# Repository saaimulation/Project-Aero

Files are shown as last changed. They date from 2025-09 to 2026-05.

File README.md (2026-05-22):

# ST0 — Front Wing Project 🏎️
Designing wings that (almost) qualify for Monaco — CAD → simulation → prototyping → iteration

This repo documents my attempt at designing a 2026-style F1 front wing in Siemens NX while learning more about aerodynamic design, CAD surfacing, manufacturing, and engineering workflows along the way.

What started as a personal aero project quickly became a massive learning experience involving CFD issues, geometry problems, redesigns, failed prints, and incredibly valuable feedback from an Alpine F1 aerodynamicist.

The goal was never to create a perfect F1 wing.  
It was to learn how real engineering development actually works:
- iteration
- problem solving
- criticism
- redesigning
- and occasionally questioning every life decision at 2am

Some ideas worked.  
Some absolutely did not.

But honestly, that’s probably the most realistic part of the whole project.

Grab a coffee (or duct tape) and enjoy the race ;)

---

## 🚦 Engineering Workflow Race

### 🏁 [Practice Lap — CAD in NX](./practice-lap-CAD) ✅ Complete
`[██████████] 100%`  
Creating the baseline front wing geometry in Siemens NX.  
The design takes inspiration from the RB19, while considering upcoming 2026 regulations.  

### 🔴 [Qualifying 1 — Red Flag](./qualifying-1-CFD) ✅ Complete
`[██████████] 100%`  
This is the first attempt of running CFD on my wing! <br>
Met with unexpected difficulties, this is a stepping stone to becoming better. 

### ♟️ [Qualifying 2 — Changing Strategy](./qualifying-2-CFD) 🔄 In Progress 
`[█████-----] 50%` <br>
After some insightful feedback from a real F1 engineer, I've started this lap with fresh tyres.   
Currently designing the 2nd iteration for my front wing!

### [Qualifying 3 — The Finish](./qualifying-3-CFD) ⏳ Planned 
`[----------] 0%` <br>
Running in-depth simulations of my upgraded ST1 front wing

### 🏎️ [Sprint Lap — 3D Printing](./sprint-3D-printing) ✅ Complete
`[██████████] 100%`  
Manufacturing a half-span model of the front wing on the Bambu A1, as well as a larger version for visuals.<br>
These parts will be used for physical testing in the upgraded wind tunnel.  
*psst. There's a free F1 wing model for you inside!*

### 🌬️ [Grand Prix — Wind Tunnel Mark II](./grand-prix-wind-tunnel) 🔄 In Progress 
`[█---------] 10%`  
Testing the 3D-printed wing in a new tunnel with flow visualisation techniques.  
The key aim is to evaluate how closely the tunnel data aligns with CFD predictions.  

### 📊 [Podium Review — Analysis & Iteration](./podium-review-analysis) ⏳ Planned  
`[----------] 0%`  
Documenting the full workflow in a 5-page executive summary report.  
The report compares CFD and wind tunnel results, highlights lessons learned, and sets directions for the next design cycle.  

---

Got feedback, advice, or better duct tape recommendations?  
I’m all ears, the whole point is to learn, improve, and share the journey! 🏎️🦇

**saaimulation**

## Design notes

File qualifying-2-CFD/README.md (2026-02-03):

# 🏎️ Qualifying 2

"ST0 ends Q1 at the 17th position, let's see if the upgrades allow for some better racing"  

Welcome back! Q2!! With feedback and some advice from an F1 engineer!!!

---

## Feedback 🛠️

After sharing ST0 publicly, I received detailed technical feedback from an aerodynamicist currently working at Alpine F1 Team (name withheld). The review focused on regulation compliance, aerodynamic intent, CAD surface quality and CFD readiness.

### Overall assessment 📊
• The concept is strong for a second-year undergraduate project and technically suitable for CFD.  
• However, I was advised not to proceed with CFD yet, as the current geometry would not provide a meaningful aerodynamic baseline.  
• Refinement of the design should come before any simulation work.

### Regulations and concept 📐
• The wing is not currently FIA 2026 legal due to being configured as a four-element design.  
• A three-element front wing was recommended.  
• Regulation volumes should be created early in the design process to define legality and aero intent from the start.  
• Using regulation volumes would also help resolve issues such as excessive span and undersized endplates.

### Profiles and spanwise loading 🌬️
• The airfoil sections were identified as too thin for realistic aerodynamic loading.  
• Spanwise loading is heavily biased towards the centreline, reduces at mid-span, then increases again near the endplate.  
• This likely creates opposing vortical structures that remove energy from the flow rather than serving a clear downstream purpose.  
• I was encouraged to think more deliberately about where the flow is intended to go, how it interacts with the tyre wake, and how it feeds the floor.

### Surface quality and CAD approach 🧩
• Several mirrored and intersecting surfaces lack tangential continuity, creating geometric discontinuities.  
• A minimum of G1 continuity should be maintained across all surfaces.  
• In professional F1 environments, G2 or G3 continuity is typically targeted, though G1 is acceptable for this project.  
• Using lofts rather than sweeps was recommended, with three to four controlled sections to maintain surface quality and reduce unnecessary curvature.

### Endplates and footplates 🚧
• The endplates were highlighted as the weakest area of the design and require significant rework.  
• Discontinuities between the main body and footplates are likely to cause local flow stagnation and contaminate downstream flow into the floor.  
• Both inboard and outboard footplates are too thin, contributing to CFD geometry issues.  
• Some regions show unexpected local thickness, likely due to filleting or surface construction errors.

### Nose and main body 🧱
• The nose was described as overly flat and undersized relative to the aerodynamic loading it generates.  
• A slightly larger and more volumetric nose was suggested to improve flow management and continuity into the wing elements.

### CFD guidance 💻
• Although the geometry could technically be meshed, proceeding with CFD now would not be productive.  
• The priority should be improving surface continuity, thickness distribution and aerodynamic intent.  
• CFD should be used later to validate a cleaner and more efficient baseline.

---

## TL;DR 🧠🏎️

• Feedback came from an Alpine F1 aerodynamicist (name withheld out of respect).  
• The wing is CFD-able but not worth simulating yet due to inefficiency and geometry issues.  
• Major improvements needed in regulation compliance, surface continuity and aero intent.  
• Endplates and thickness distribution are the main weaknesses.  
• Concept is strong for my level and worth refining before CFD.

Despite the inefficiencies, the feedback concluded that the work is very strong for my level and demonstrates a high degree of ambition and iteration, well beyond a typical second-year undergraduate project.

## What’s Next – ST1 Roadmap 🧭🏎️

The next iteration (ST1) will focus on refining the concept into a regulation-led, CFD-ready baseline.

• Rebuild the front wing around FIA 2026 regulation volumes to ensure legality from the outset.  
• Reduce the configuration to a three-element wing and redefine element stacking and slot gaps.  
• Increase airfoil thickness to support realistic aerodynamic loading and improve flow robustness.  
• Rework spanwise loading distribution to remove opposing vortical structures and define clearer downstream intent.  
• Redesign endplates and footplates to improve continuity, reduce stagnation, and deliver cleaner flow to the floor.  
• Improve surface quality across all components, targeting full G1 continuity with smoother loft-driven geometry.  
• Adjust nose geometry to improve volumetric continuity and flow management into the wing elements.  
• Clean and simplify CAD topology to remove unintended thickness changes and prepare for meshing.  

Once these changes are implemented, ST1 will be used as the first meaningful CFD baseline, focusing on pressure distribution, flow attachment, and qualitative validation before further optimisation.

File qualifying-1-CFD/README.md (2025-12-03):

# 🏎️ Qualifying 1  

"And here we are, lights out on the next stage of Project: Aero! The CAD lap is in the books, ST0 has rolled out of the garage, and it’s heading straight into the CFD arena. No wind tunnel, no factory-scale computers. Just me, SimScale, and a very nervous laptop fan."  

This part of the project is all about finding out if my RB19-inspired, regulation-legal, student-version-of-NX front wing can actually generate downforce… or if I’ve just built a very stylish drag machine.  

### 🎯 Goals  

- Import the geometry into SimScale and generate a clean mesh.  
- Run airflow simulations at baseline F1 speeds (~50 m/s to start).  
- Visualise pressure, velocity, and streamlines to understand behaviour.  
- See if the slot gaps and flap angles really do their job, or if I’ve engineered the world’s most expensive desk fan.  

### 🛠️ Tools  

- **SimScale** (meshing + solver + post-processing in one platform)  

---

Think of this as Q1 in qualifying: the aim isn’t to smash records yet, but to get a solid lap on the board. Once the pipeline works, we’ll push harder in Q2 and Q3 which means higher speeds, setup tweaks, and hopefully a lot more downforce.  

### 🧠 What I Expect to See  

- A clear pressure differential across the wing (high pressure above, low pressure below), confirming it generates downforce rather than lift.  
- Streamlines remaining attached through the slot gaps, if they detach too early, the wing stalls and performance drops off a cliff.  
- Evidence of Y250 vortex structures forming near the central section, helping control airflow downstream.  
- The outer flaps biasing flow outward around the tyres (like the RB19), reducing wake turbulence and drag.  
- Boundary layers that stay thin and attached, if they thicken or separate too much, I’ll know my flap angles were too aggressive.  

If I see these features, I’ll know the design philosophy was on the right track. If not… well, back to the CAD garage for ST1.  

---

# SimScale notes

So we begin. Starting off by importing my STL file into the software.

### Import and scale

<div>
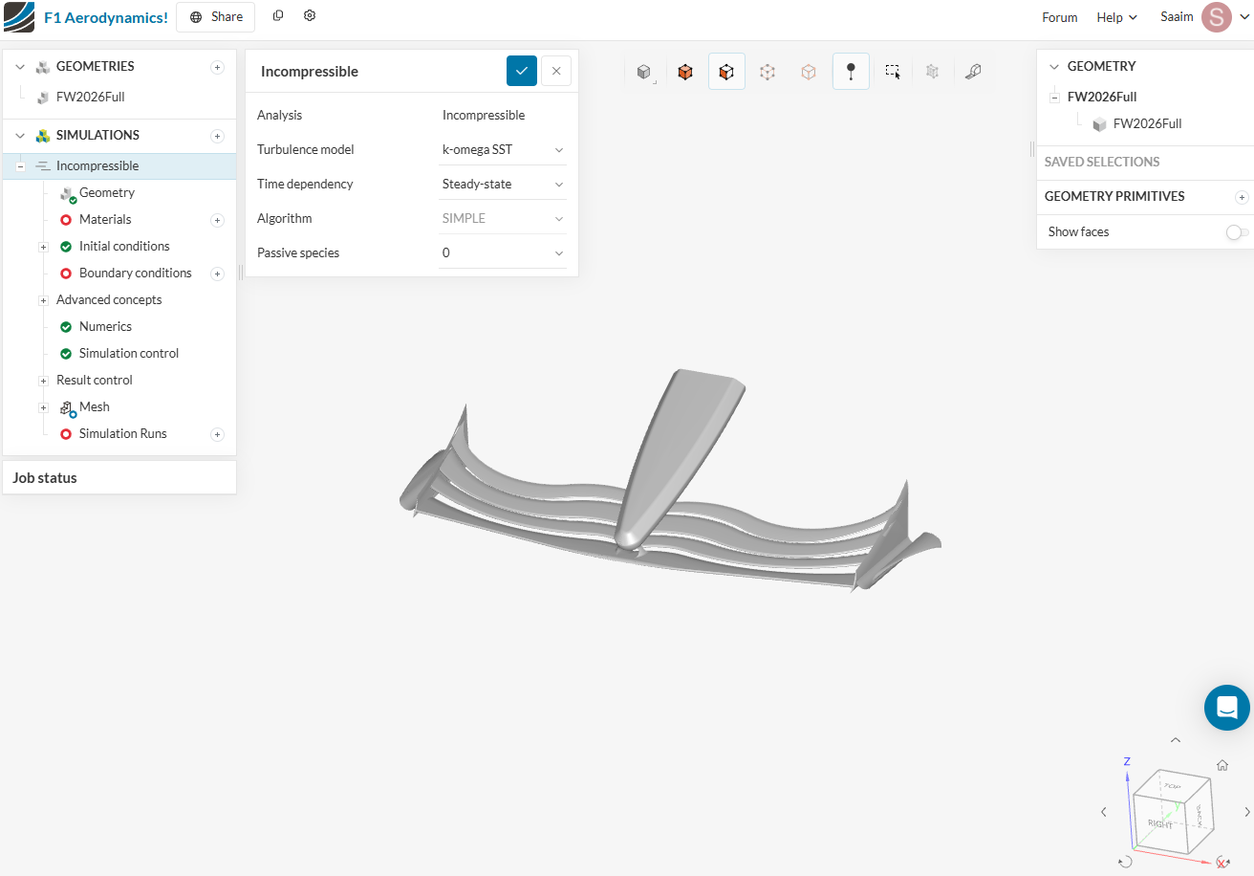
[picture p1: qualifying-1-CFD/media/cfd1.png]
Initial import
  
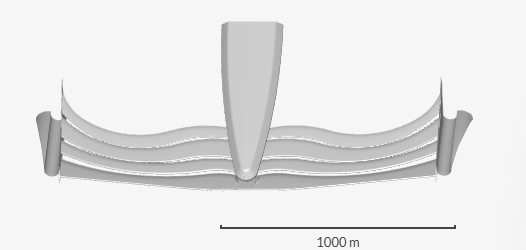
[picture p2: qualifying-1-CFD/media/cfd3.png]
Scale check
  
</div>

Scaled the model by a factor of **0.001** to convert m → mm.

<div>
  After scaling
</div>

### Setup

Created an external flow volume and set up an incompressible simulation.

<div>
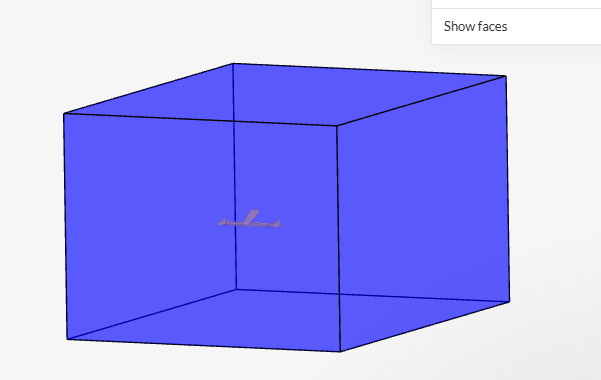
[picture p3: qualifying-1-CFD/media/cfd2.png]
External flow region
  
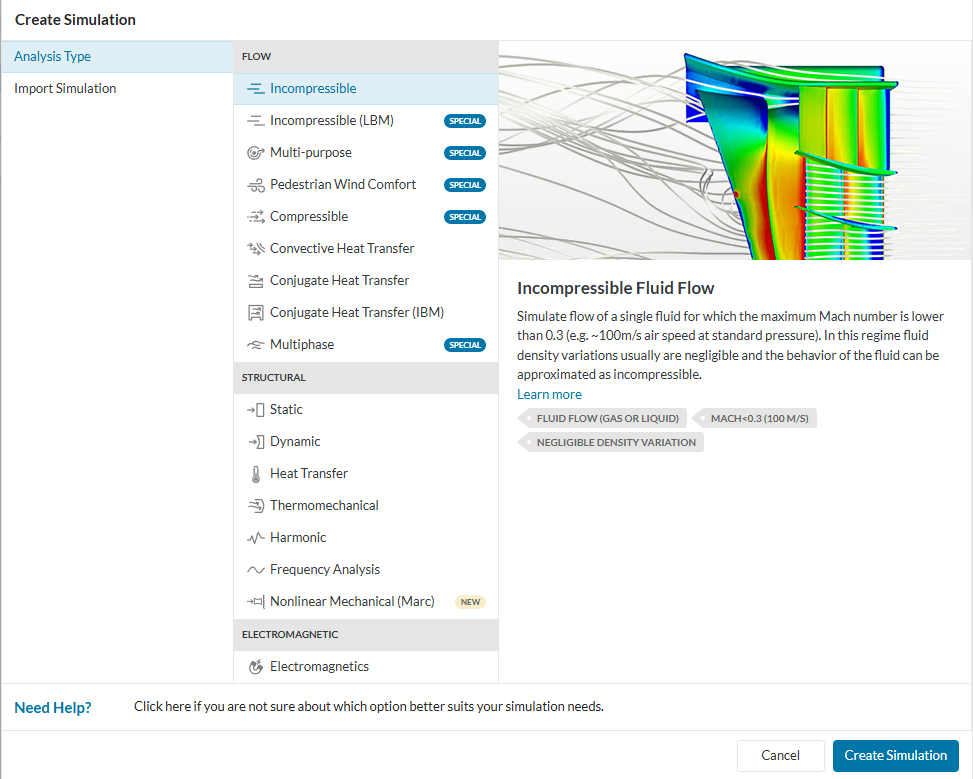
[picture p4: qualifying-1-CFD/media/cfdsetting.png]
Simulation settings
  
</div>

### What went wrong 🤕

Then came the errors. Many of them.

<div>
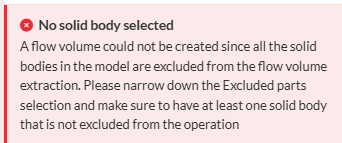
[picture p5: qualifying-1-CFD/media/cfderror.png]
Error 1
  
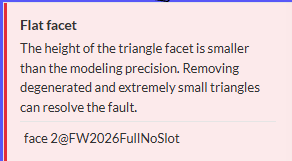
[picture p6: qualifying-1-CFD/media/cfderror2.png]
Error 2
  
</div>
<div>
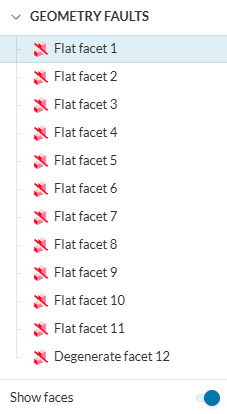
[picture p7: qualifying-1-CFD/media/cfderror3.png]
Error 3
  
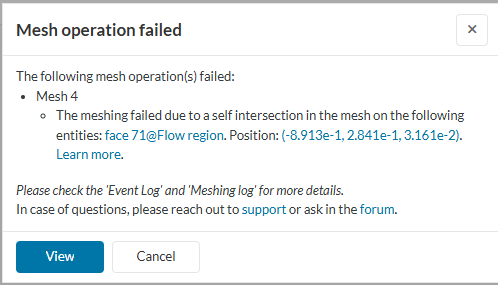
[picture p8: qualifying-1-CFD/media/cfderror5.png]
Error 5
  
</div>

Tried everything I could think of: tutorials, docs and forums. Tweaked the model, repaired faces, changed the flow region, removed tiny slots.  
Still no success.  After four days it was clear the blocker was geometry integrity, not the physics setup.

### Resources I used while debugging 🤖

- SimScale forum thread on [assigning materials to original geometry vs flow region](https://www.simscale.com/forum/t/my-original-geometry-and-flow-region-assigning-materials/99541/3)
- Official tutorial: [Formula Student car — Edit a copy](https://www.simscale.com/docs/tutorials/formula-student-car/#edit-a-copy)
- Knowledge base: [Intersections in the model](https://www.simscale.com/knowledge-base/intersections-in-model)
- Forum discussion: [Flat facet error](https://www.simscale.com/forum/t/flat-facet-error-and/90315)
- Video guide: [External aerodynamics in SimScale](https://www.youtube.com/watch?v=WsPy_TJotv4)
  
---

### Taking a step back ⏪

I was spending too long debugging and accepted the root cause: my CAD needed work.   
It felt like going backwards, but fixing the geometry was the fastest way forward. 

Unfortunately, ST0 did not qualify in Q1...

# Back to the garage for Q2!

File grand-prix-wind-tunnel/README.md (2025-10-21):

# 🌬️ Grand Prix — Wind Tunnel Mark II

*"Welcome to race day! In five lights time, the Project Aero Grand Prix will be starting. It's lights out and away we go!"*

Hello again! This time the final lap has finally begun! Designing and building the Mark II wind tunnel to test the 3D-printed 2026 front wing. Smoother flow, cleaner data, faster feedback. The real race starts here.

## 🧠 Understanding Wind Tunnels 

First thing on the agenda: RESEARCH   

I have to find out how these wind tunnels work! Learning and thinking about how to design and produce it is a step in every process of bringing something to life!
So here is that I have learned:   
1.

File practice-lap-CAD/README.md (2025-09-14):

# 🏁 Practice Lap — CAD  

“And away we go! The first lap of Project: Aero. The garage doors are open, the tools are out, and the focus is on turning rough ideas into geometry that can actually be tested.”  

Hi, Saaim here👋 Welcome to the practice lap! This stage begins with the 2026 F1 regulations 📜 The new rules bring narrower cars, simplified aero and movable elements, all designed to reduce dirty air and keep racing close. Within those constraints, the target is to create a baseline front wing in Siemens NX.  

NX was chosen as the baseline CAD tool after advice from industry engineers, with CATIA as a natural future step once I’m confident in NX.

I thought about including the new active aerodynamics — Z-mode for high downforce in corners and X-mode for low drag on the straights — but decided to keep it simpler for now. That can be a future project 👀  

So before any sketches or CAD, it’s time to check the rulebook!

### 📜 FIA 2026 Front Wing Regulations (condensed)

- Maximum width reduced to **1900 mm** (100 mm narrower than 2022–25).  
- Must be a **single assembly**: mainplane, flaps, endplates, pylons.  
- Up to **4 profiles** allowed, with a fixed flap rotation axis.  
- Endplates must cover the FIA’s mandated reference boxes in both top and side views.  
- Smooth transition into the nose, with limited fillet radius (≤ 25 mm).  
- Active aero (Z/X modes) is permitted, but not included in my first version.  

**What this means for me**  
- I need to design within a narrower span and tighter FIA boxes.  
- Endplates must stay simple and legal; no overcomplicated tricks.  
- Flap geometry has to respect the fixed hinge axis.  
- Active aero is allowed in the regs, but I’ll skip it for now.  
- My target is a clean, rule-aware baseline wing that can be tested in CFD and the tunnel.  

📂 The full regulations can be found in this repo:  
`/practice-lap-CAD/fia_2026_technical_regulations.pdf`

---

### 🔎 Visual references (FIA concept)

**Front view**  
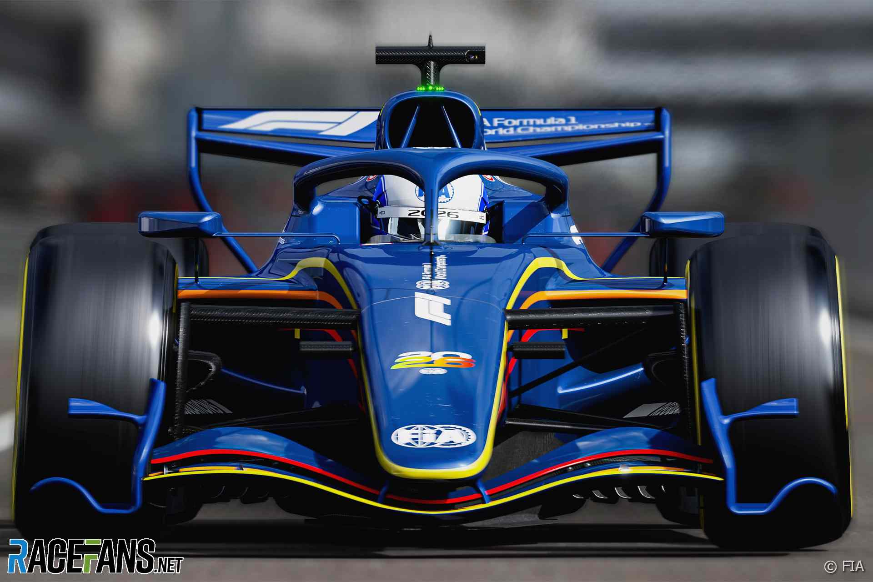
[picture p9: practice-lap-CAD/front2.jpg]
Front view


**Three-quarter renders**  
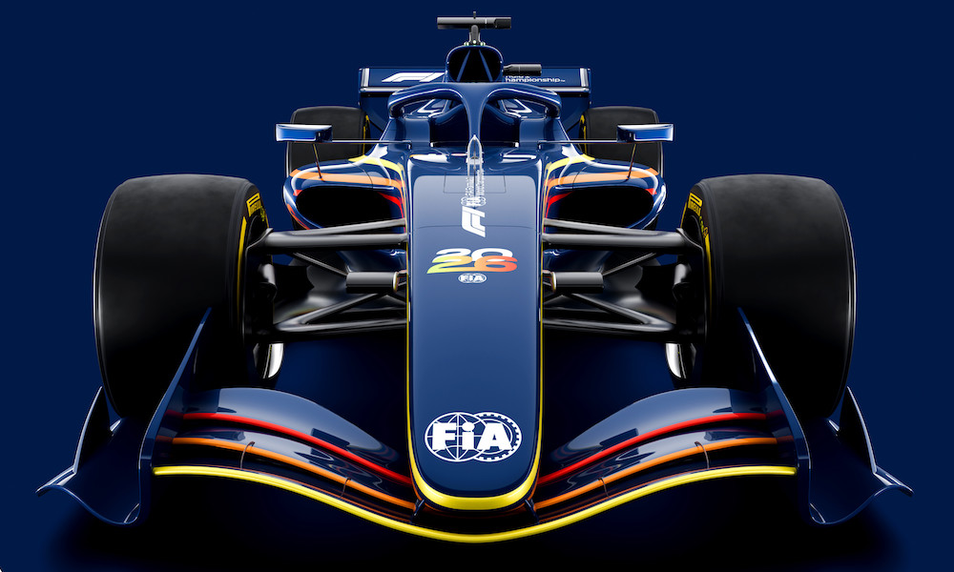
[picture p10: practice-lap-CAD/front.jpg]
3/4 render
  
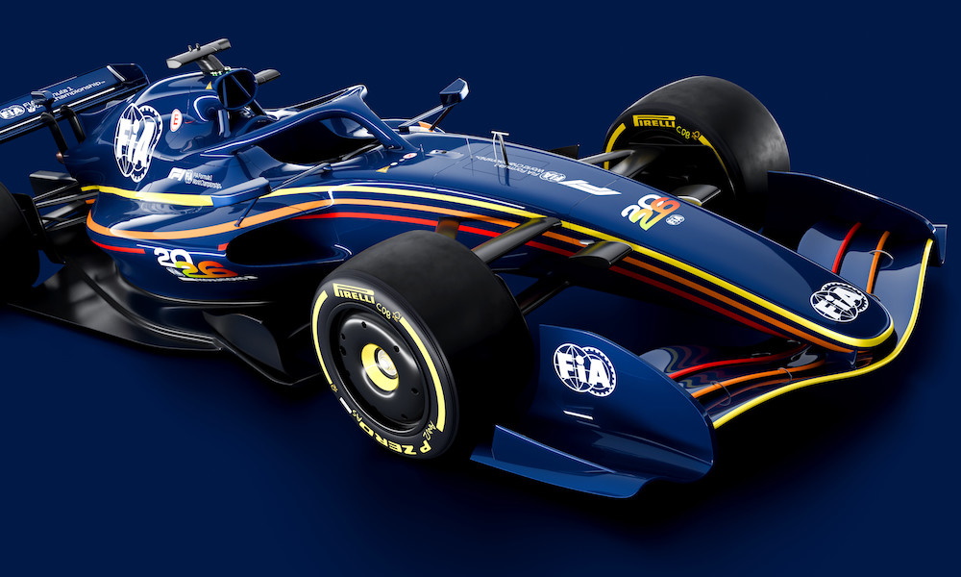
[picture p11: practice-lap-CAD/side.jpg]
Side view


---

## 🧭 Build plan & scaling

I’ll model a **full-size half-span** wing in NX (so 950 mm if the full span is 1900 mm). From there I’ll produce two physical versions:

1) **Wind-tunnel test article — half-span at 25% scale**  
   - Size: **237.5 mm** span (fits my 250 mm build plate for the Bambu A1)  
   - One-piece print if possible, otherwise 2-piece with alignment pins  
   - Used for tunnel testing and comparisons to CFD

2) **Display piece — full-span at ~35% scale**  
   - Size: **~665 mm** span (for photos, not tunnel)  
   - Printed in 3–4 sections with pins & glue
   - Lets me show the full geometry without needing a huge tunnel

If the tunnel ends up smaller, I’ll drop the half-span scale to 20% to keep things practical!

---

## 🎥 Short explainers I used

- F1 2026 aero overview: https://www.youtube.com/watch?v=HIEHRR7Sy1g  
- What changes & why it matters: https://www.youtube.com/watch?v=fXPZdvkKfbA  
- Another clear breakdown of the concept car: https://www.youtube.com/watch?v=5FyFerbm6Js

---

### 🏎️ RB19 Inspiration  

The RB19 was the most dominant car of the ground effect era, winning almost every race in 2023. Its front wing was a big part of that success — not because it looked crazy, but because it was refined everywhere that mattered.  

Some highlights worth stealing:  
- The flaps tapered toward the endplate which helped push air neatly around the front tyres.  
- The outer section had just enough curvature to bias the flow outward and clean up the tyre wake.  
- The stacking line across the elements was smooth so vortices stayed stable instead of breaking up into chaos.  
- The centre section near the nose was kept simple and low drag so the wing could work hardest at the outer span.  

For my project I will use the 2026 FIA concept as the baseline but I will sneak in some RB19 flavour. Flap tapering, outer sweep and a smooth stacking line are all on the menu. The aim is not to build Red Bull’s secret sauce but to let the most successful design of recent years inspire a student version that can survive CAD CFD and eventually my wind tunnel.  

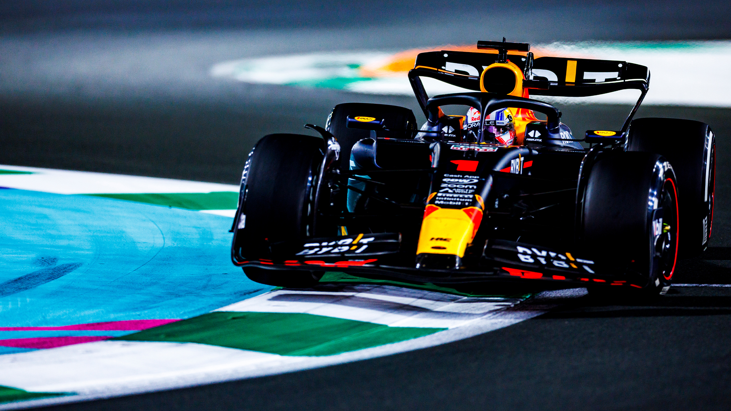
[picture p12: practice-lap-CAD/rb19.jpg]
RB19 Front View


## 🧩 The CAD (finally)  
Here is what you are all waiting for. FINALLY, Saaim is actually going to model and show the front wing. I would also take this opportunity to say, that this is my first time using NX.  

Ever...  

Talk about jumping into the deep end, but that’s what makes it exciting 👀  

I started by adding some expressions so that scaling down would be a lot easier, which are shown below:  

NX Expressions

---

## Reference Images

To guide the design, I brought in FIA 2026 concept renders and RB19 references (which were very hard to find).  
This way I can stay within regulations while adding some of Red Bull's innovation!

### Top View Comparison
<p align="center">
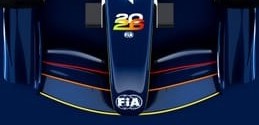
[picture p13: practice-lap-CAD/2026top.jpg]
2026 Top
  
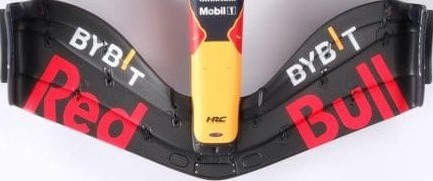
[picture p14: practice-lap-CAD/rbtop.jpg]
RB19 Top
  
</p>

### Front View Comparison
<p align="center">
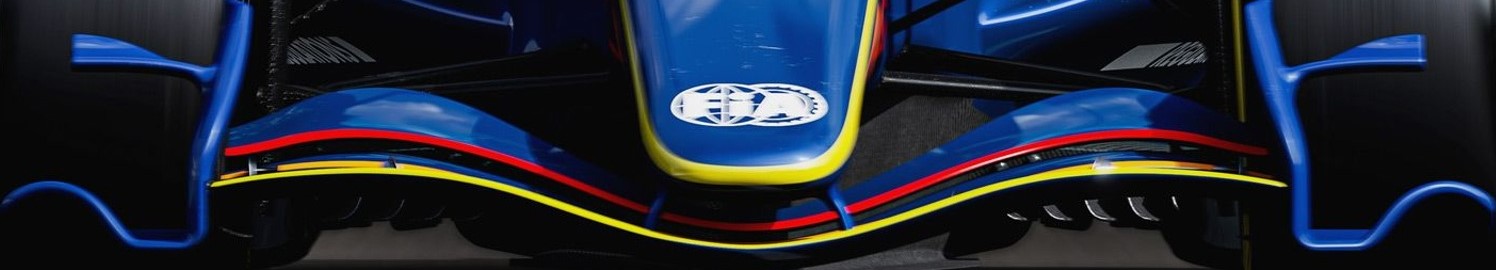
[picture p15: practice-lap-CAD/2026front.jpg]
2026 Front
  
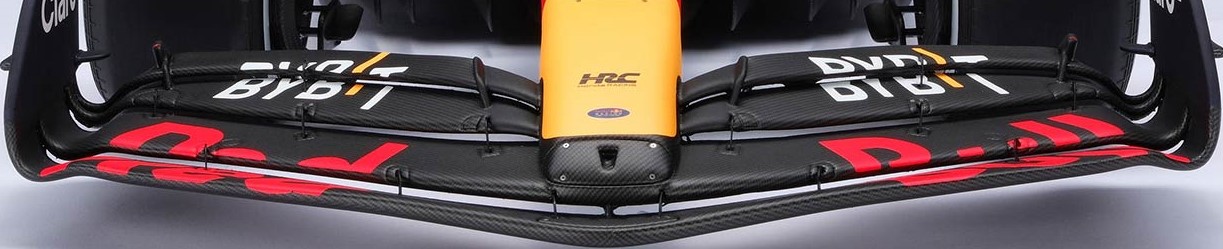
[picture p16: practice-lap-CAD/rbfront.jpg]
RB19 Front
  
</p>

So here we go! Loaded up NX, reference images in hand, tons of time. 

"this should be okay"

SAID NO-ONE EVER!!! As I was trying to insert my reference images, I was met with an amazing greeting:

heartbreak

I quickly realised that the student version of Siemens NX had a limited number of tools, since it is not meant for commercial use.  
This meant that I couldn't curve flaps and move them at my will. So I utilised angles, filleting edges and just tried to find loopholes in what I could and couldn’t do.  

---

## 🚦 The Start  

I started off by making the nose of the car, which turned out terrible:  

<p align="center">
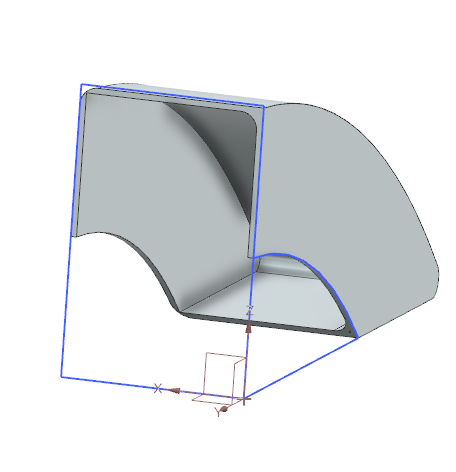
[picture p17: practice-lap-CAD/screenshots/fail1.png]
  
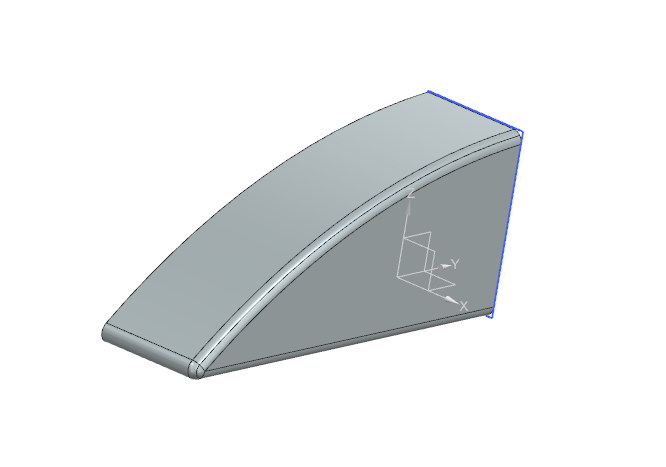
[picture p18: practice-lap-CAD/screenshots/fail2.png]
  
</p>  

After trying for an hour, I realised it would be better to start with the mainplane instead.  

With regulations stating the wing can only be 950 mm wide, I made the mainplane 800 mm, leaving 150 mm for the endplate design.  

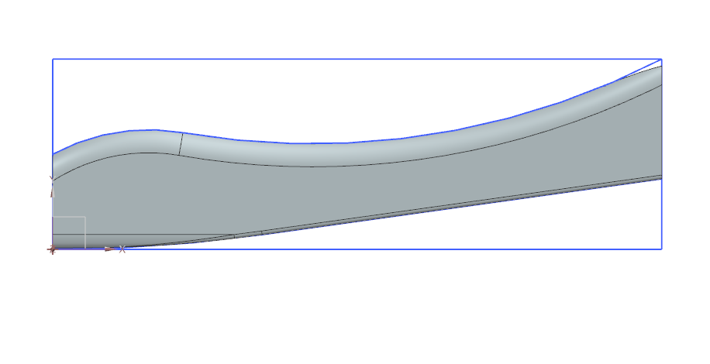
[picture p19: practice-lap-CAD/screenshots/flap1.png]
flap1
  

This had fillets of radius 5 mm at the front and 50 mm at the rear to create downforce (at least in theory, the CFD will confirm).  

Since I couldn’t use curves, moving faces or image references, I learned how to use datum planes. Creating planes at angles allowed me to get closer to the RB19 look.  

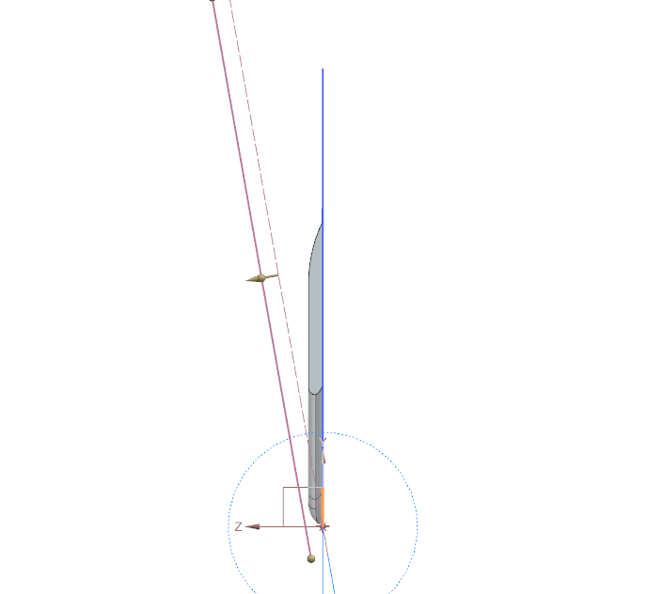
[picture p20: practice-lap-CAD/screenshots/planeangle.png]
planeangle
  

For reference, here’s the Audi 2026 concept, which made it easier to grasp the new regulations and shapes of the flaps, nose and endplate:  

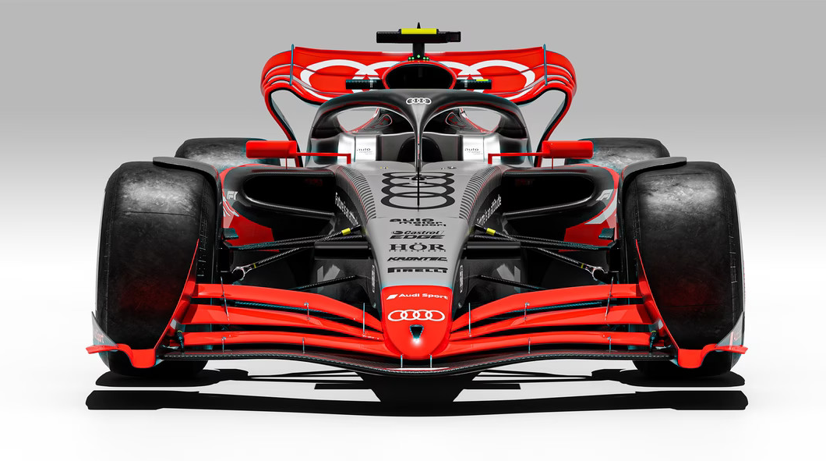
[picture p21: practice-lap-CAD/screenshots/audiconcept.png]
audiconcept
  

---

## 🪂 Flaps  

The second flap was sketched on a 5° datum plane, using splines and arcs, then extruded to ~8–10 mm thickness (in line with regs).  

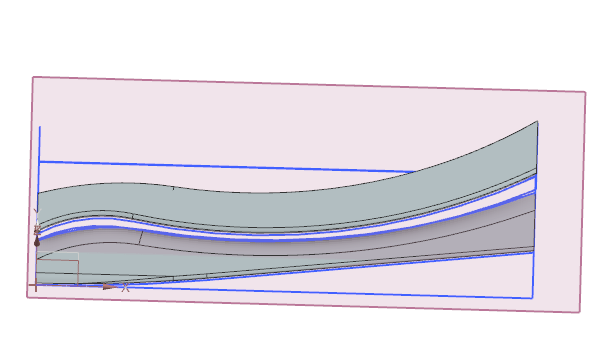
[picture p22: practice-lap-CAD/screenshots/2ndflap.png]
2ndflap
  

One FIA rule is that there should be no visible gaps from the top view. My first attempt vs fix:  

<p align="center">
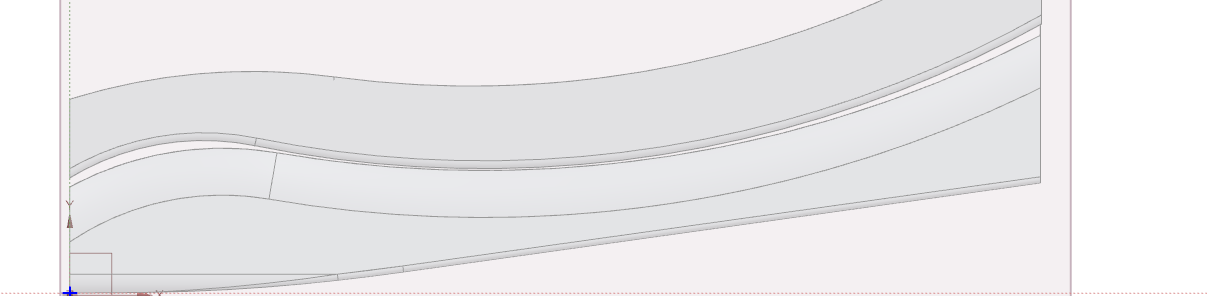
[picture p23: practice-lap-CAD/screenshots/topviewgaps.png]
  
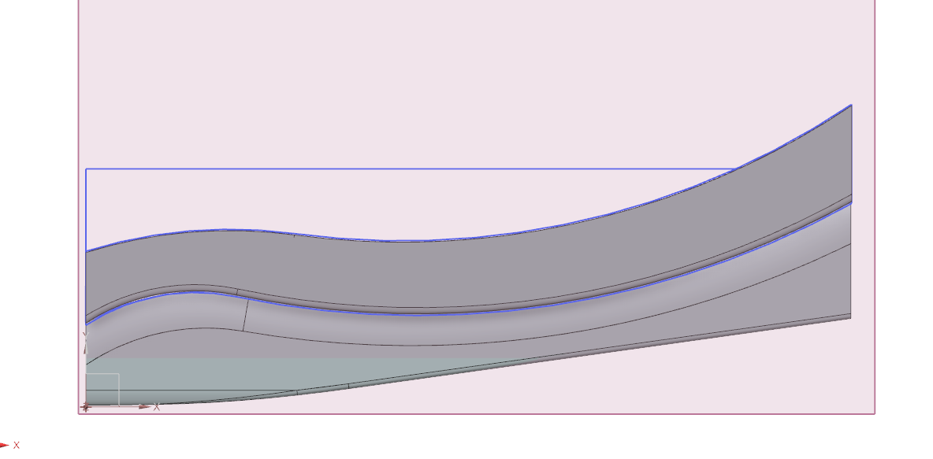
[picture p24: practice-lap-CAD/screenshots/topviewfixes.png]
  
</p>  

I continued the same method for the 3rd and 4th flaps, taking inspiration from the RB19.  

<p align="center">
  
  
</p>  

Overall, I was happy with the result. The process became simple once I figured out how to build the first flap.  

---

## 🧱 The Endplate  

This part was tricky. Without curve tools, I created a basic 6 mm thick extrusion united with the flaps:  

basicendplate  

At first, the last flap didn’t connect:  

<p align="center">
  
  
</p>  

For the outer curve, I used arcs and splines, then a triangular cut with a 3 mm fillet radius.  

<p align="center">
  
  
</p>  

To improve airflow and allow outwash past the tyres, I added slots with 80 mm fillets. These help with drag reduction and vortex management.  

<p align="center">
  
  
  
</p>  

---

## 👃 The Nose  

Back to the beginning. Once I had more confidence, the nose became straightforward. A couple of rectangles and arcs on the XY plane, extruded at 10°, plus some fillets gave me this:  

<p align="center">
  
  
</p>  

In the 2026 concept, only the mainplane connects to the nose. The flaps remain separate for active aero.  

connection  

---

## 🏁 Final Model  

After mirroring across the ZY plane, I finally had the full wing.  

<p align="center">
  
  
</p>  

finalangle  

---

## 🖤 Carbon Fibre, Why Not?

Because every project deserves a photoshoot.  

<p align="center">
  
  
  
</p>  

<p align="center">
  
  
  
</p>  

---

## 📂 Download the CAD

For anyone who wants to check it out or 3D print it, here’s the model export:  

➡️ [Download FW2026Full (.stl)](./FW2026Full.stl)

This STL is the full mirrored version of ST0.  
It’s ready for printing and can also be imported into most CAD and CFD tools.  

If you’d like the parametric file with sketches and planes, let me know! I’ll add a STEP version later.

## 📚 Summary  

This stage of Project: Aero has been fun and insightful. With no tutorials, textbooks, guidance or external assistance, I used passion and creativity to build ST0, the first of many iterations.  

Even with the limitations of NX, I was able to:  
- Adhere to FIA regulations  
- Think about aerodynamic efficiency  
- Add RB19 features
- Learn a new software
- Use my creativity to design something from scratch

I hope to continue this work and make it better, and challenge myself to even harder concepts. 
Thank you for reading! If you had any questions or any advice, please reach out to me on LinkedIn!

The next step is CFD testing, which you can find here:  
[Project-Aero/qualifying-lap-CFD](../qualifying-lap-CFD/)  

### That’s all for now. See you in qualifying 😉

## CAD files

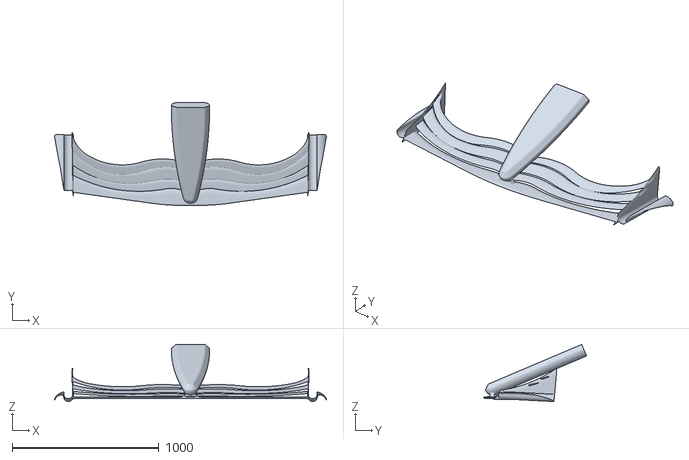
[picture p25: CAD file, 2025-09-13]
practice-lap-CAD/FW2026Full.stl
1851.8 x 702.3 x 388.8

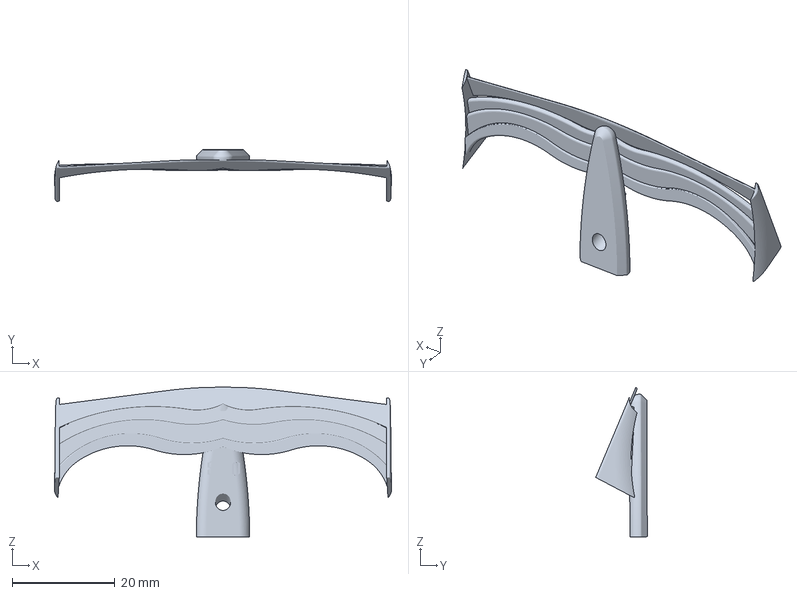
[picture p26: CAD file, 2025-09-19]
sprint-3D-printing/FWKeyUpdated.3mf
65.6 x 10.1 x 29.1 mm

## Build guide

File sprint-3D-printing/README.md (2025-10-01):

# 🏎️ Sprint Lap – 3D Printing  

*"Box now! Box! Box now box, for hard! Uh, STAY OUT, STAY OUT!"*  

Hello again! This time we’re doing something a lot easier: **3D printing the front wing!**
This should be quick, welcome to the sprint!  

---

## 🎯 Filament choice  

I bought CF PLA (carbon fibre PLA filament) for the print.  
[Link to the exact one I used](https://www.amazon.co.uk/FLASHFORGE-Filament-Dimensional-Lightweight-Heat-Resistant/dp/B0DHZQ8812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).  

It’s only 10% carbon fibre but at £20 it’s decent for testing.  
(and good for a broke university student)

---

## 🖥️ Slicing setup  

Opened the ST0 model in Bambu Studio. Not my first time slicing, but definitely the first time at this scale.  

<p align="center">
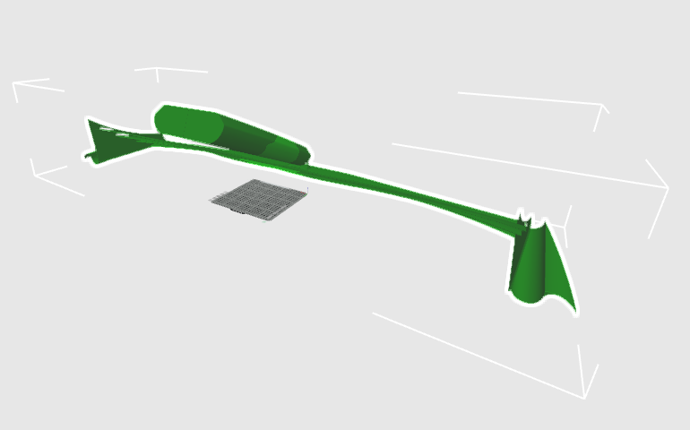
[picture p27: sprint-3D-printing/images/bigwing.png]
  
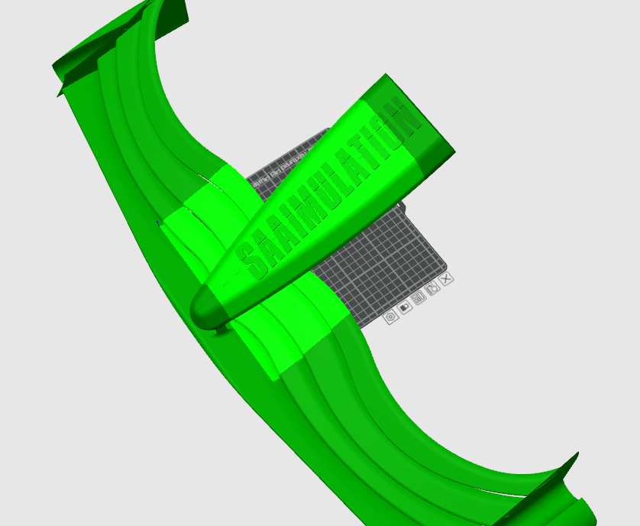
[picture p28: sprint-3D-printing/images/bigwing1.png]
  
</p>  

I cut the model into sections and placed them on separate build plates:  

<p align="center">
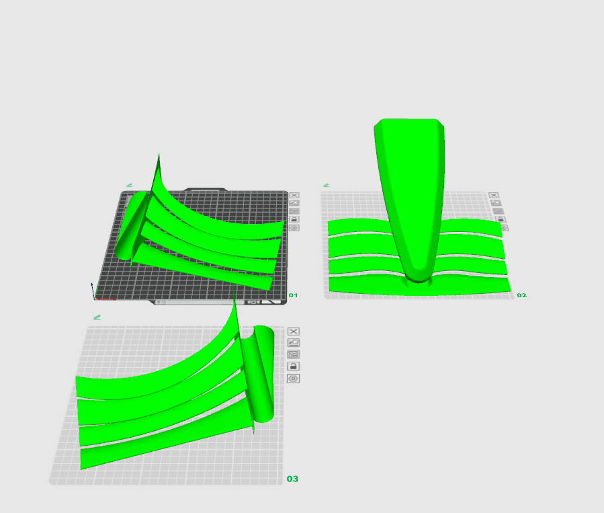
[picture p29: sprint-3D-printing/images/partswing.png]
  
</p>  

---

## 💥 First failed attempt

The first section was estimated at 8 hours… but not even 30 minutes in, disaster struck.
Supports failed, the print warped, and almost 400 g of filament was about to be wasted.

<p align="center">
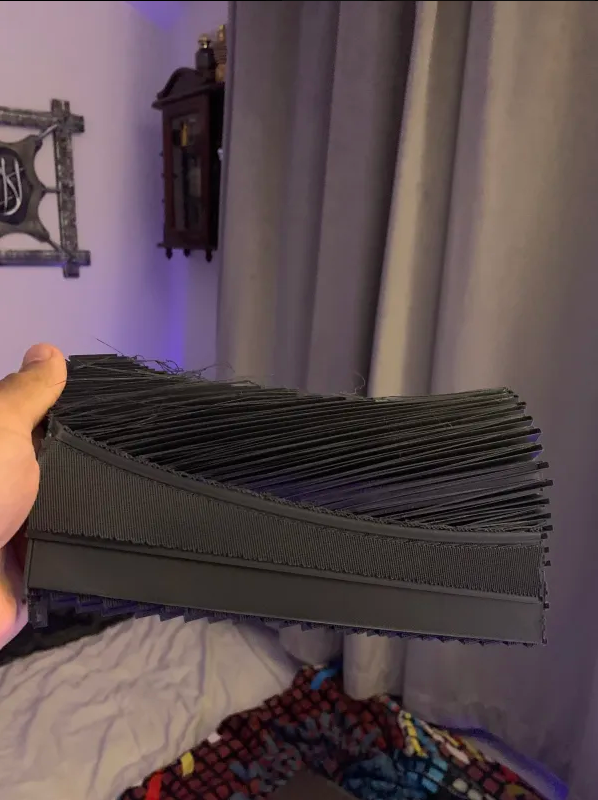
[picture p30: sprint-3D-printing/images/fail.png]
  
</p>

And honestly… this meme sums it up better than words:

<p align="center">
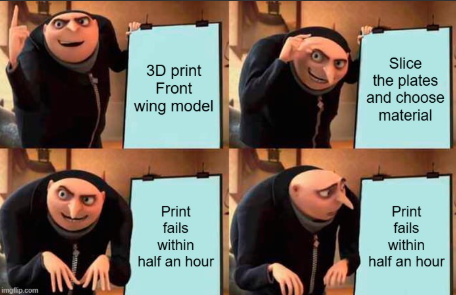
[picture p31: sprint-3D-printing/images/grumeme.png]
  
</p>

Lesson learned: at 30% scale, the flaps were only a few millimetres thick. Even if the print had finished, sticking the pieces together would’ve been a nightmare.

---

## ✅ New plan  

I decided to split this into two separate goals:  

1. A **display model** — larger scale, purely for my room.  
2. A **test model** — smaller, around 10–15% scale, for the wind tunnel.  

# 🖼️ Display - to admire in my room...

<p align="center">
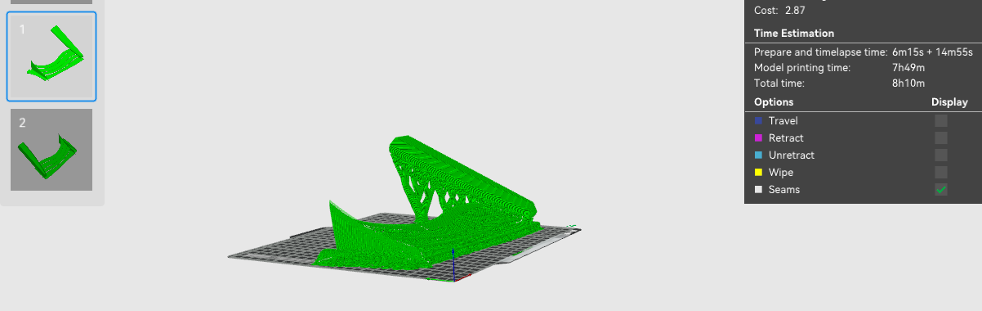
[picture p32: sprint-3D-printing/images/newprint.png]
  
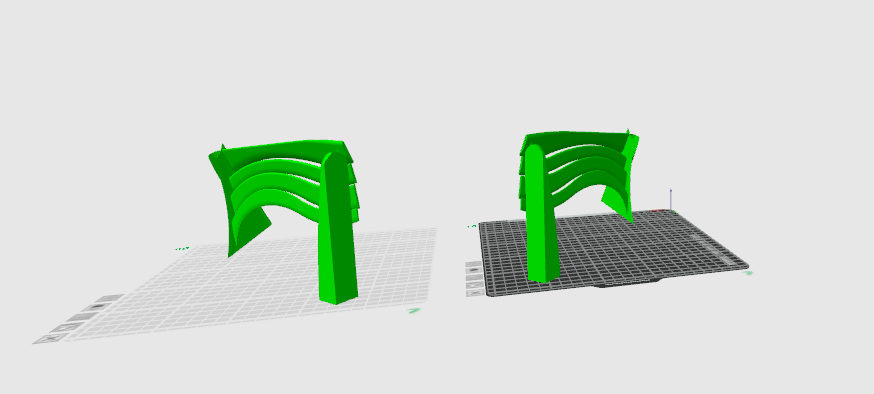
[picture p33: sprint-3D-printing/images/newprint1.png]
  
</p>  

Rotating the wing nose-up reduced the supports under the thin flaps and saved print time + material.  

Final slicer check:  

<p align="center">
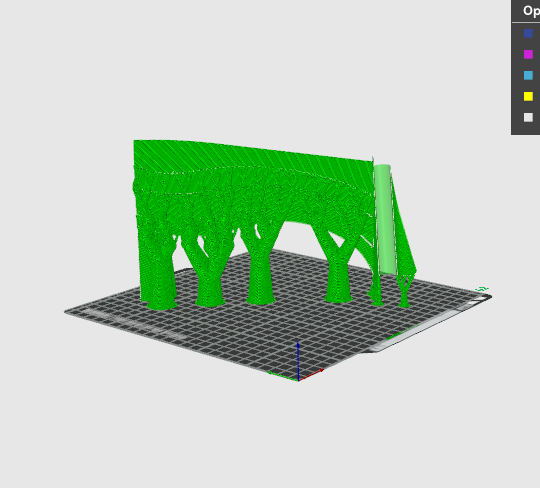
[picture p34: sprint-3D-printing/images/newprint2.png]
  
</p>  

Now we wait 8 hours… fingers crossed this time.  

---

Couldn't sleep because of the whirring fans from the printer, but when it was done, it came out pretty well!  

<p align="center">
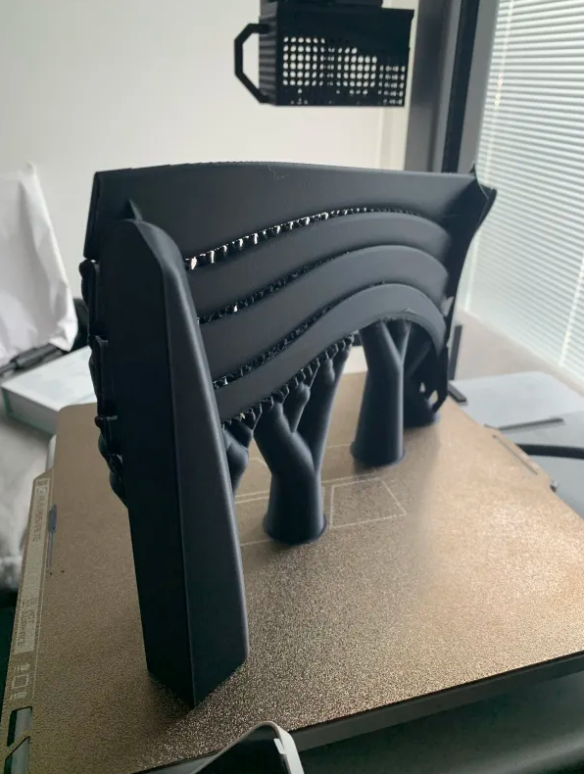
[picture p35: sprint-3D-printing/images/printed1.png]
  
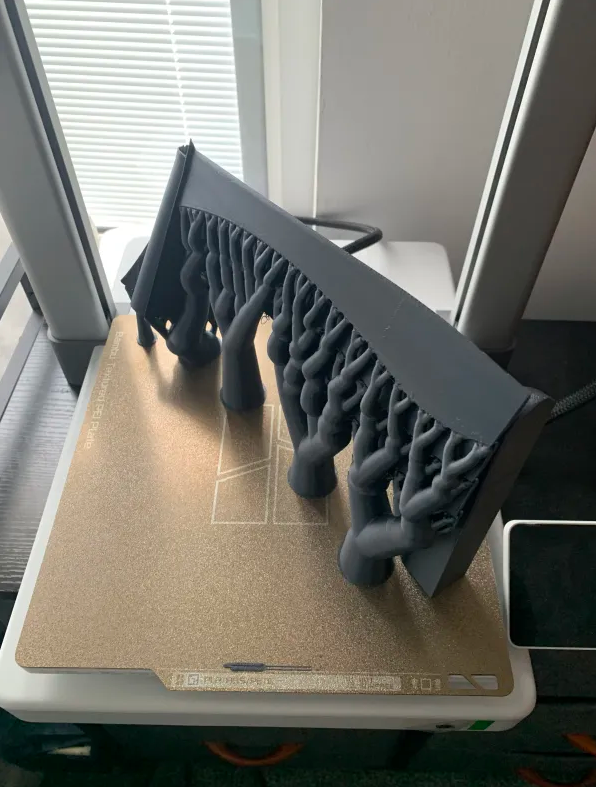
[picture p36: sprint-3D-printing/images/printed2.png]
  
</p>  

There was a lot of material used on the supports, but much less than the previous attempt because I managed to lower the infill and branch diameter!  

Here is how the print came out:  

<p align="center">
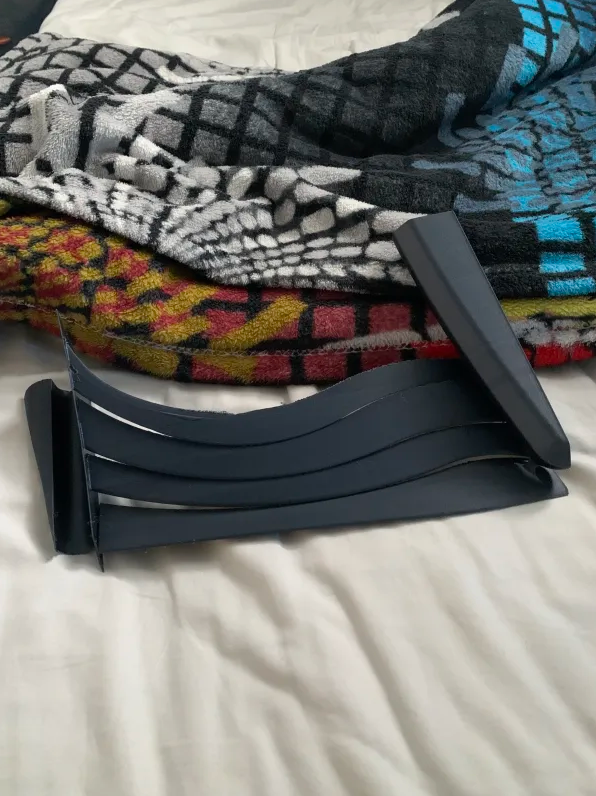
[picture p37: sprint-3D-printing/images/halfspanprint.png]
  
</p>  

I realised one potential issue, a bit too late, which was the nose of the wing only being connected by a thin wall in the model.  

<p align="center">
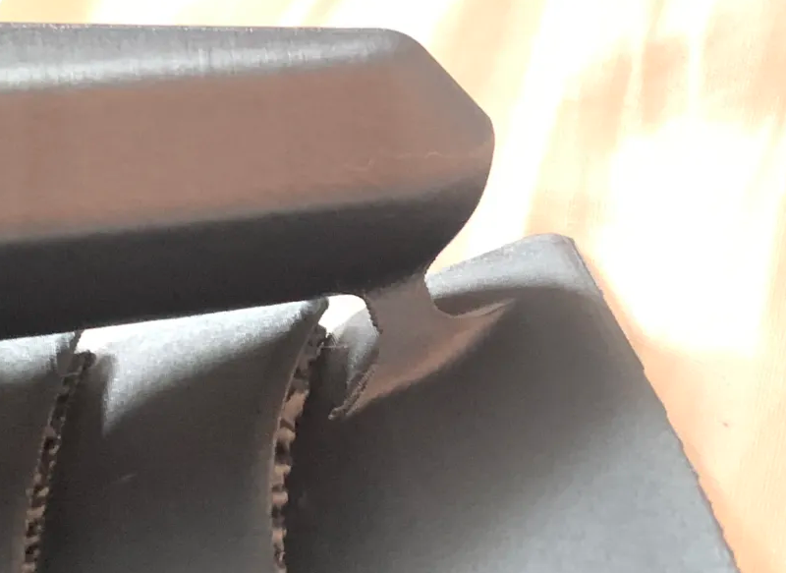
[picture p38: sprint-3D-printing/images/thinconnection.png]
  
</p>  

This is reflected in the 3D printed version too, but it will be fine after I join the two halves together, giving it more support.  
The edges have some imperfections, due to the small fillet angles on the back of the flaps, which became even smaller after scaling down.  

After printing the other half, I used superglue to assemble the wing.  
I originally planned to add mechanical connectors (rods and holes), but the flaps were too thin to handle drilling without breaking.  

<p align="center">
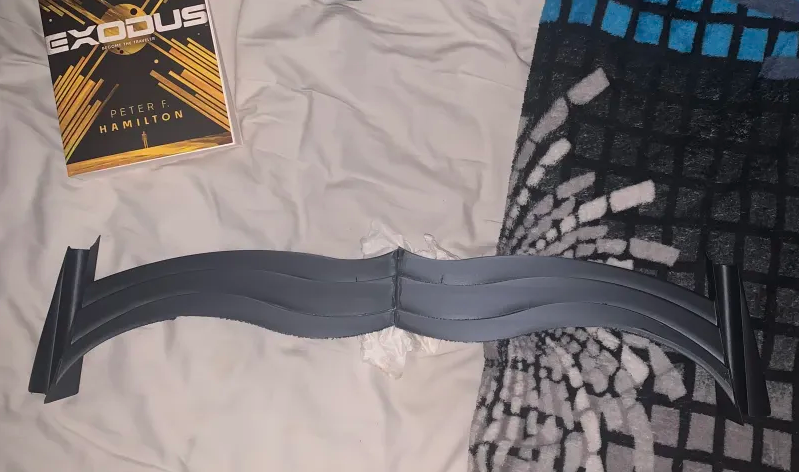
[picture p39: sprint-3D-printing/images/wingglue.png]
  
</p>  

Here is the completed assembly at 35% scale:  

<p align="center">
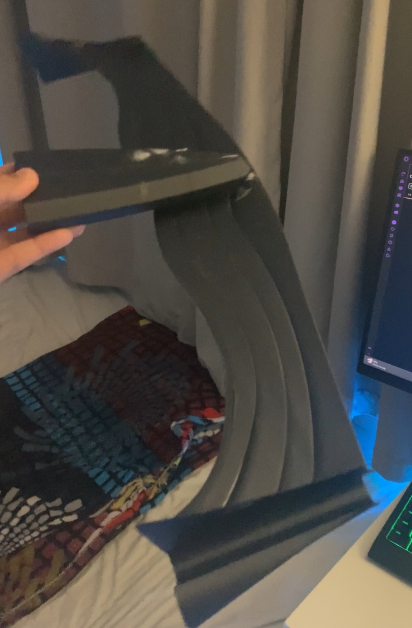
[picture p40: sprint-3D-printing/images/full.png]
  
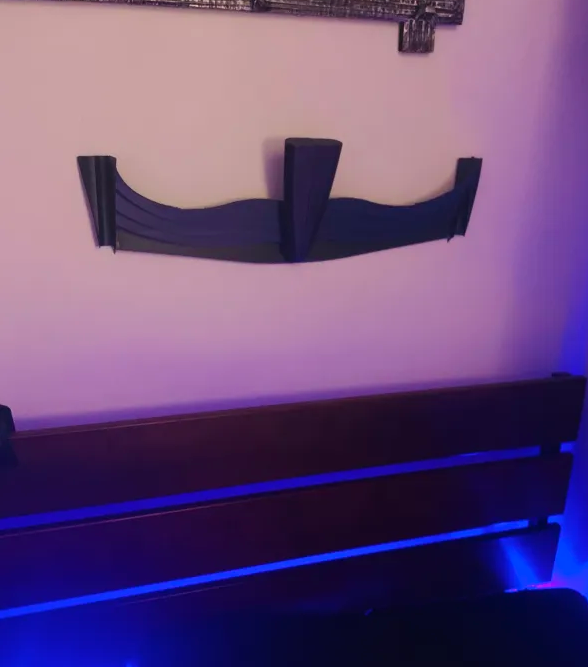
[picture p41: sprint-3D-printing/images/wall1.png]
  
</p>  

For mounting, I used 3M Command strips to attach the wing securely to the wall as a display piece.  

This part of the project taught me a lot about practical assembly and iteration:  
- How to optimise support structures and infill during slicing to reduce material waste.  
- How thin-walled aero components behave when scaled for printing, and the compromises needed for strength.  
- The effort required when transitioning a digital CAD model into a physical prototype suitable for display or testing.  

At 35% scale, the wing is already a huge presence in my room. It gives perspective on the real challenge in F1!<br>
Where teams build 60% scale wind tunnel models that are several metres wide.<br>
It’s incredible to think of the engineering effort that goes into those full aerodynamic programmes.  

# 🔬 Test - to visualise aerodynamics...  

In Formula 1, teams have their models at 60% scale, to balance cost and accuracy. However, I am trying to balance my time and my sanity.<br>
So I will be attempting to print the wing at a 10-15% scale. This way I can get more accurate results, whilst restricting the space needed to build the wind tunnel. 

To make it work, I added a reinforced block at the nose–flap junction.  
This secures the structure and gives me an area to drill into, so the model can be pinned to the wind tunnel wall for testing.  

<p align="center">
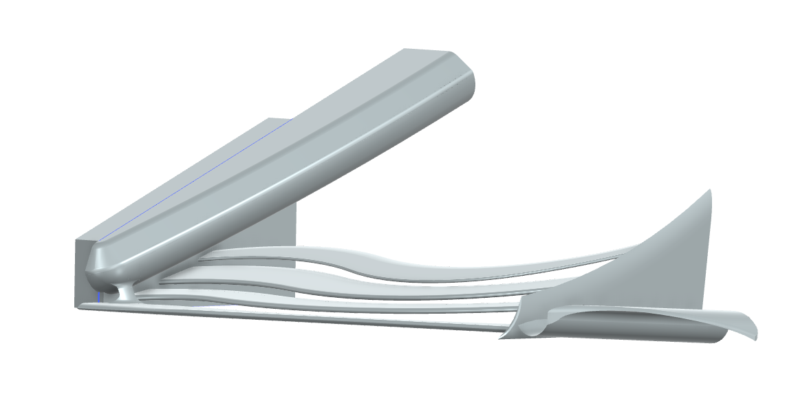
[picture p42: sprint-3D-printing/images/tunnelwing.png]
  
</p>  

Deciding on half-span vs full-span was tricky.  
In the end, half-span works better for flow visualisation. With symmetry, I don’t need to worry about yaw effects, and I can focus purely on the flow.  

---

### ⚠️ First Attempt  

Printed at 12% scale, 30% infill. 
It failed after 10 minutes…  

Great, locked up on turn 1...

Time to reiterate!!

---

### 🔎 What Went Wrong  

1. **Endplate too thin**: at 12% scale it became translucent in slicing.  
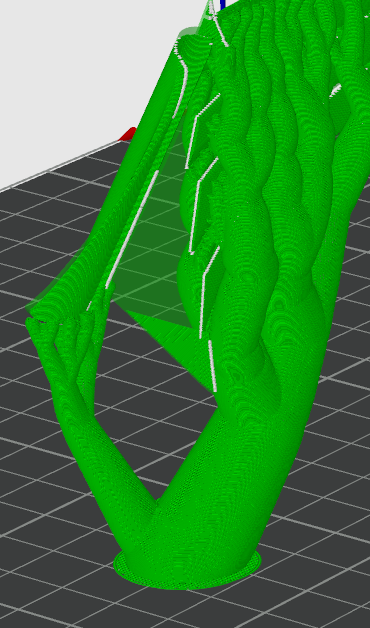
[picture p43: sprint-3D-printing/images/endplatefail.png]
     

2. **Old model**: I accidentally used an earlier version with inaccurate fillets and gaps.  
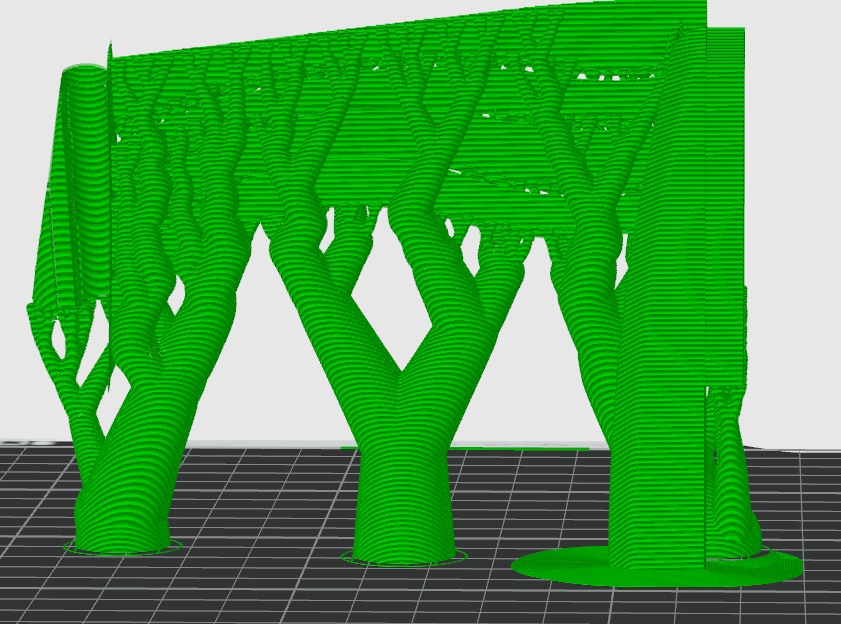
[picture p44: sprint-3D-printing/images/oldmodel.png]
     

3. **Reinforcement block too small**: not enough surface area for drilling holes.  

---

### ✅ Fixes in the Next Iteration  

1. Thickened the endplate and tweaked the fillets to maintain aerodynamic efficiency.  
2. Used the updated CAD model, enlarging thin chamfers and angles for printability.  
3. Extended the reinforcement block to cover a wider base area.  

<p align="center">
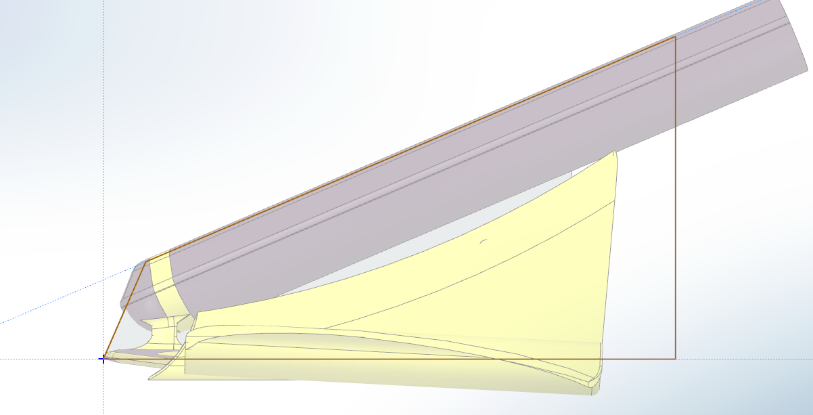
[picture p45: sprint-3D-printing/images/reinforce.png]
  
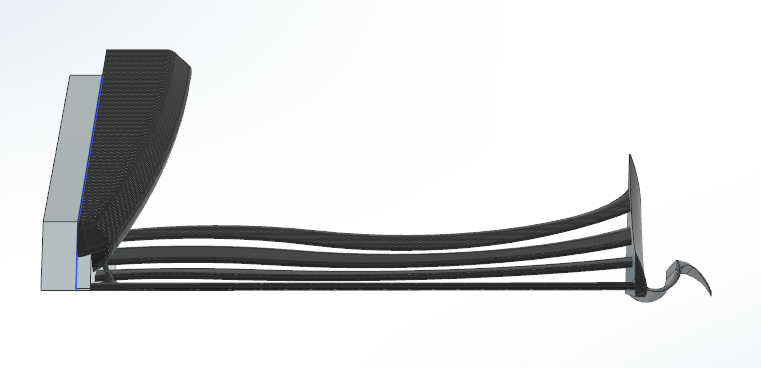
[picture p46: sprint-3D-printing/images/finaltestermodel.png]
  
</p>  

I also adjusted the slicer settings:  
- Increased the support angle threshold  
- Increased branch diameter for sturdier supports  

### 🏁 Final Print and Finishing  

<div style="display: flex; gap: 10px;">
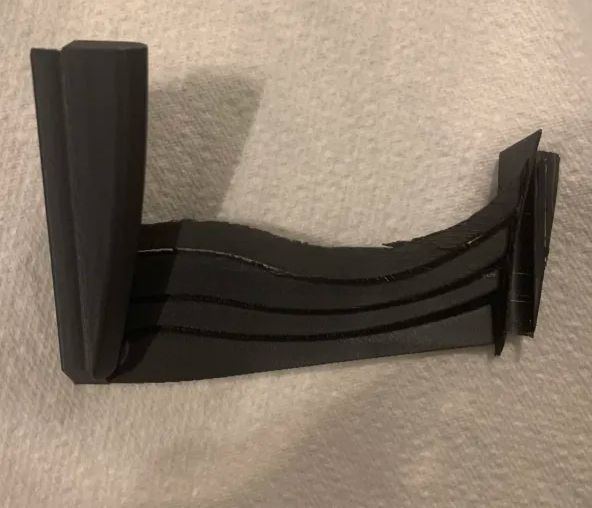
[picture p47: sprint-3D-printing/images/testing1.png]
  
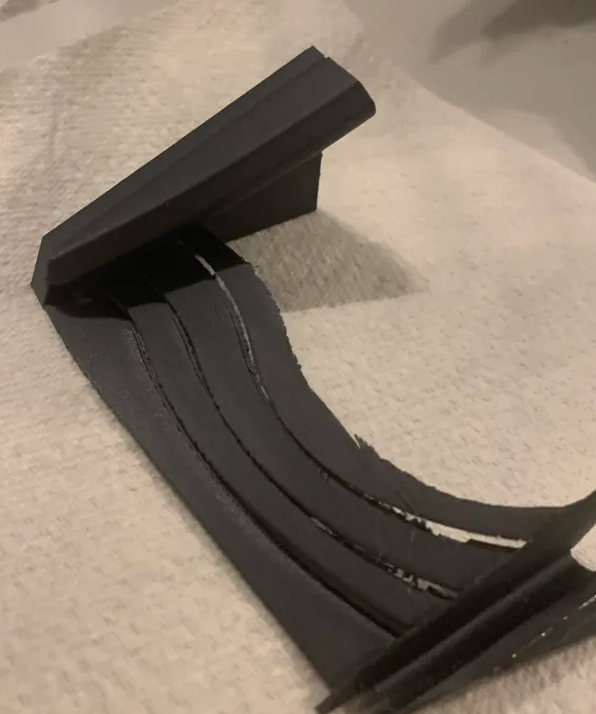
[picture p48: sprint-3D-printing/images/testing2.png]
  
</div>  
This time it worked! The size was right. The flaps came out a little rough around the edges, so I used sandpaper to smooth everything down.  
<br>
<div style="display: flex; gap: 10px;">
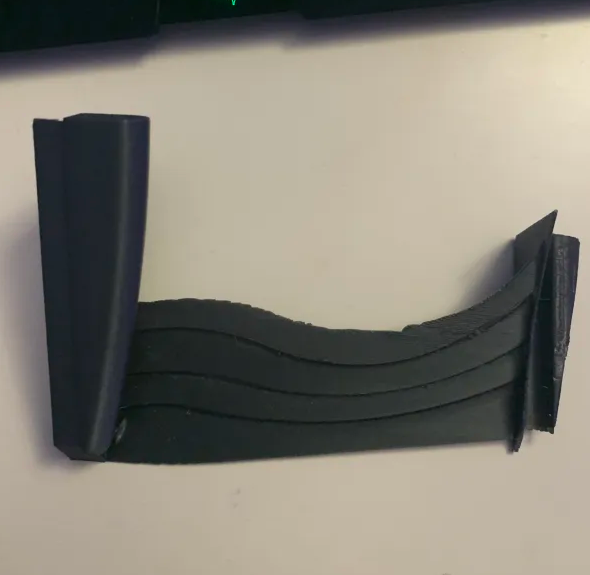
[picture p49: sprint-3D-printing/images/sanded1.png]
  
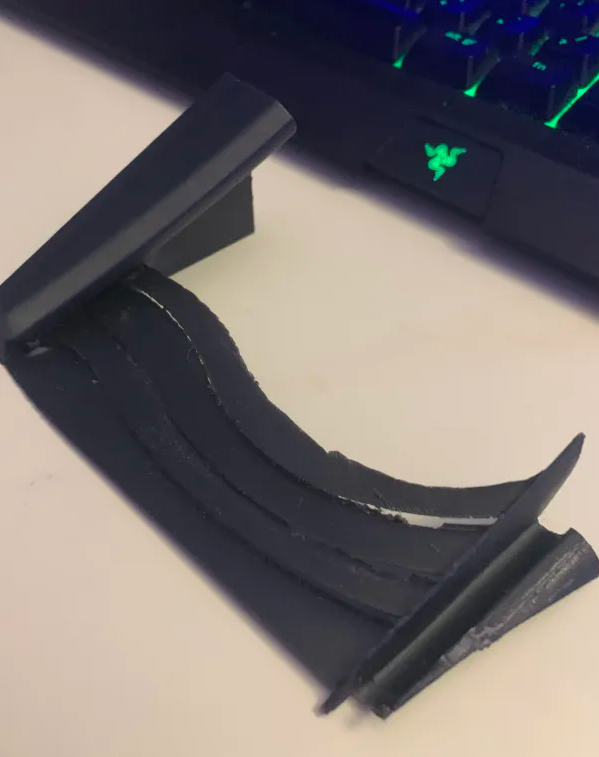
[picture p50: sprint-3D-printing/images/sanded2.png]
  
</div>  
Much better! The edges are smoother, and even the micro print failures won’t have a noticeable effect when I run this in a wind tunnel.  
<br>

### 📚 What I Learned  
- You always have to learn from your mistakes, just like Tony Stark.  
- Iteration is how most of my progress is made.  
- I realised that failure genuinely means that I am learning.  

# 🎁 BONUS! Mini F1 Wing Keychains!!  

In the middle of doing these prints, I had an idea:  
what if I scaled the front wing *all the way down* into a keychain?  

At first it sounded like a gimmick, but it actually became a valuable mini project.  
It tested how well the design scaled, how durable the geometry was at very small sizes, and how engineering can be shared in an accessible, hands-on form.  

---

## 🔧 Redesign for strength  

To survive at 5% scale, the model needed changes:  
- Reduced fillets on the flaps (aero efficiency is pointless at keychain scale).  
- Removed the thin connection walls from the nose to the mainplane.  
- Lowered the nose and embedded the flaps directly for strength.  

<p align="center">
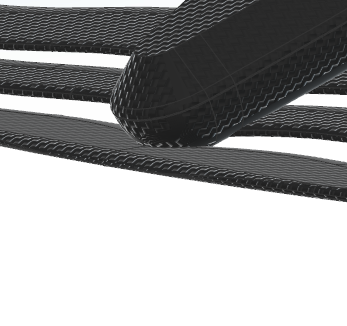
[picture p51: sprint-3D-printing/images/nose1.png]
  
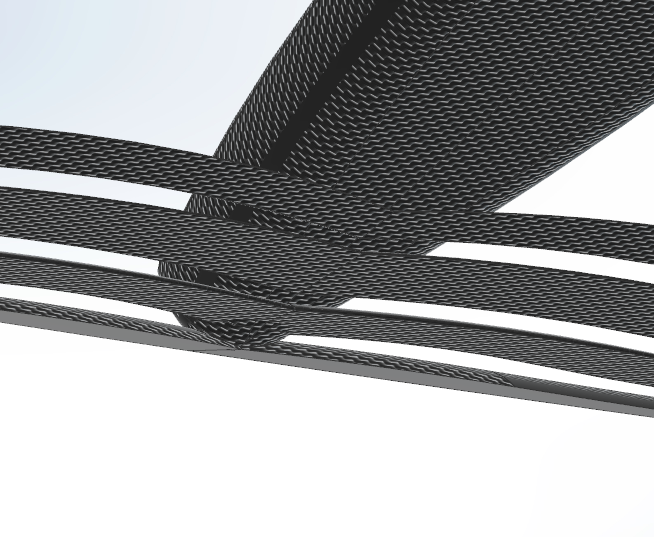
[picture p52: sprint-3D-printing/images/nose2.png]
  
</p>  

Slots in the endplate were also removed, since they would have weakened the print.  

<p align="center">
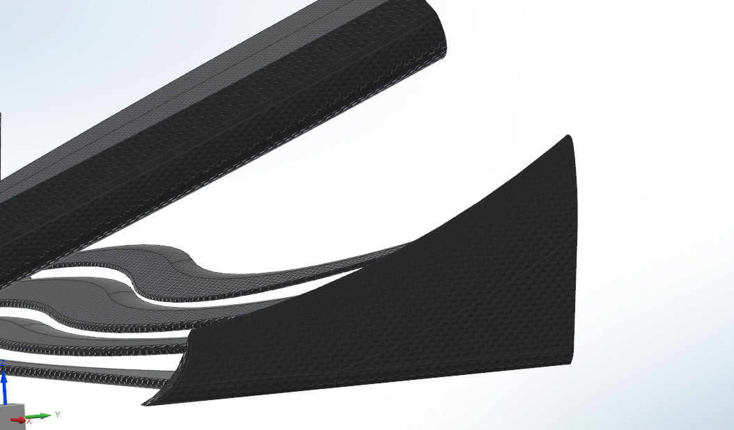
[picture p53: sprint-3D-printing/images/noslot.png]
  
</p>  

Finally, I added a small cut for the keyring loop.  

<p align="center">
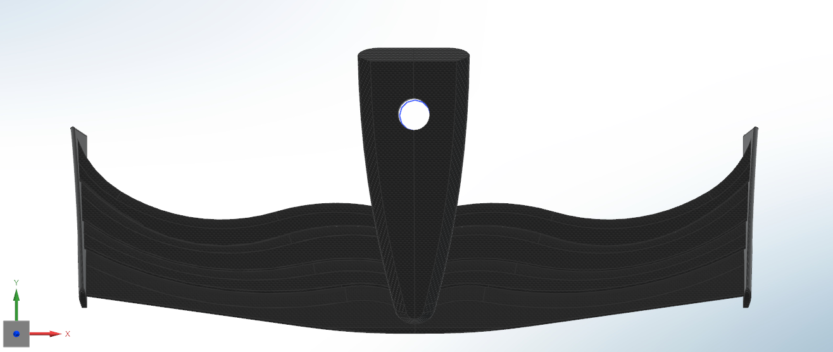
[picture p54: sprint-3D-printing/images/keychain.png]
  
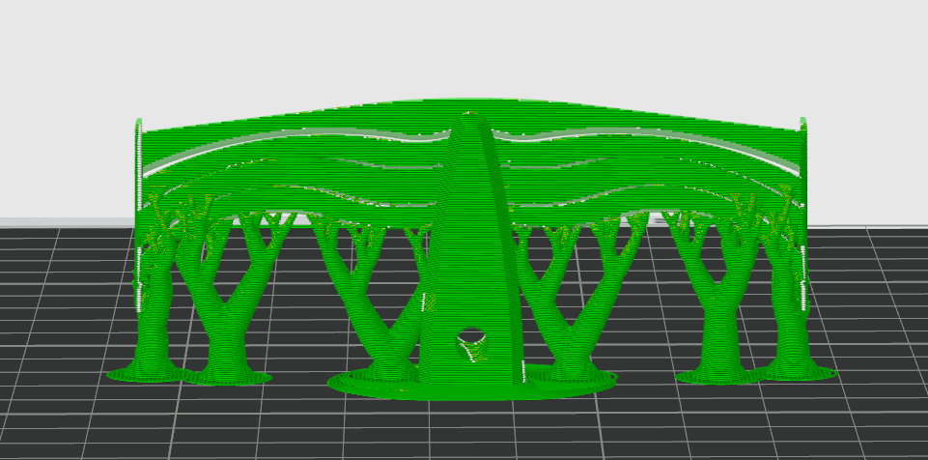
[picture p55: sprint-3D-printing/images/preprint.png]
  
</p>  

---

## 🖨️ First print  

Printed at **5% scale**:  

<p align="center">
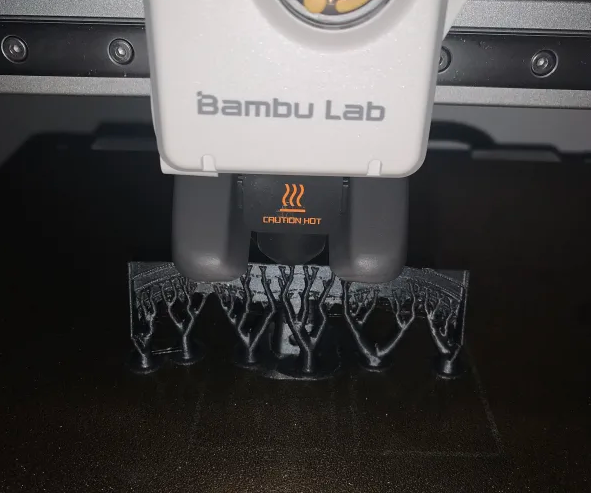
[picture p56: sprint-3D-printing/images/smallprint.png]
  
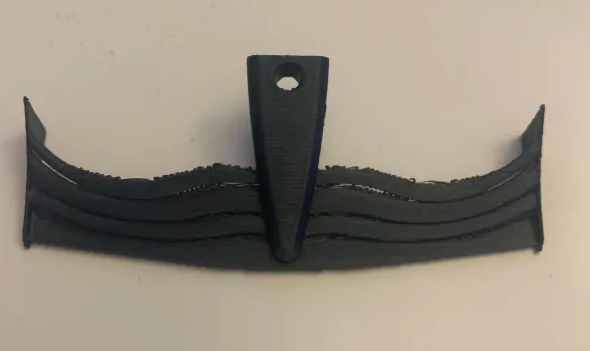
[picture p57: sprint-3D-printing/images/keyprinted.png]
  
</p>  

Surprisingly, it was flexible and strong. But the edges were too rough and the gaps between flaps looked messy.  

<p align="center">
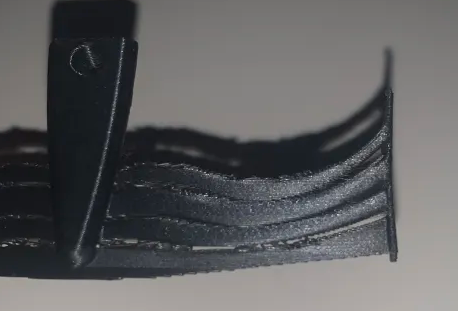
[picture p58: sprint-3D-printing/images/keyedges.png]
  
</p>  

---

## ⚙️ Iteration  

I went back to the CAD, removed all edge fillets, and closed the gaps between the flaps.  
This improved both the look *and* the strength.  

The second version was printed at **4% scale** (yes, even cuter).  

<p align="center">
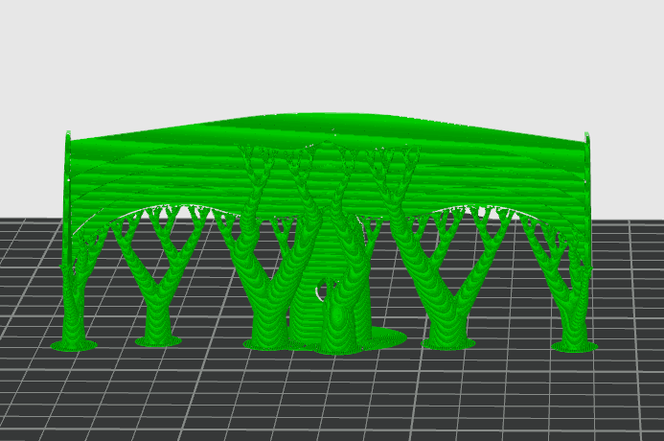
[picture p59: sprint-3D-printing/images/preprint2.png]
  
</p>  

---

## 🏆 Results  

After **31 minutes** and just **3 g of filament**, I created the final version of this F1 wing keychain.  

This served as both a **durability test** and a way to share the project in a pocket-sized format.  
Instead of keeping the design locked away on CAD or CFD plots, it’s now something people can hold, use, and remember.  
Being visual proof of my CAD skills, and giving them as a gift to any interviewers I happen to meet. A nice gesture!

<p align="center">
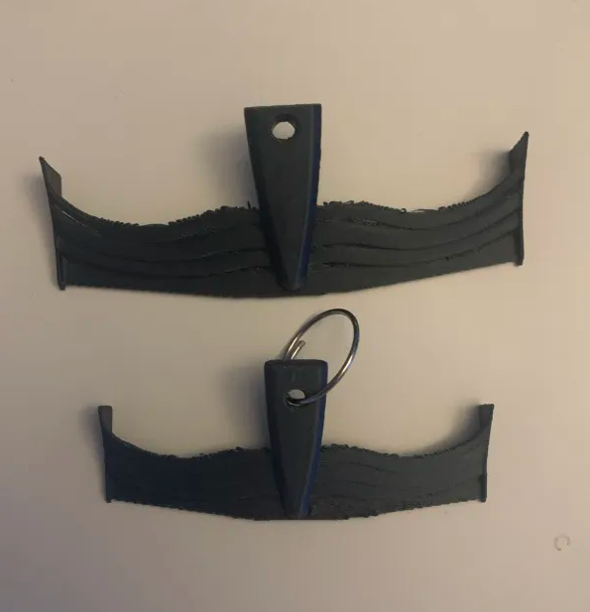
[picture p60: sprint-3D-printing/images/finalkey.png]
  
</p>  

The bottom wing is the smaller, refined version. It still has some rough edges, but at that scale there isn’t much more I can do.  
Potential improvements could come with a 2 mm nozzle upgrade on my Bambu A1.  

---

This was a mini project to make engineering more accessible and shareable.  
Here’s the model if you’d like to print one yourself:  

👉 [FWKeyUpdated.3mf](./FWKeyUpdated.3mf)  

## 📚 Summary  

This sprint lap was all about turning CAD into something you can actually hold. From failed attempts to finished parts, I learned more about scaling, durability, and how small design choices show up in the real world once printed.  

Across the different versions, I was able to:  

- Create a display model at larger scale for visual impact  
- Produce a wind tunnel model at a 12% scale for testing and CFD correlation  
- Design a mini keychain version as a durability test and a way to share engineering in an accessible, pocket-sized form  

Key takeaways:  

- Printing taught me how thin fillets and small gaps can make or break a design at scale  
- Orientation and slicing strategy are just as important as CAD design when it comes to structural success  
- Iteration is everything, each print failure gave me insights I wouldn’t have learned in CAD alone  

This stage has been both fun and technical, combining creativity with practical engineering. The wing isn’t just geometry on a screen anymore, it exists in carbon fibre PLA, glued together, keychained, and even tunnel-ready.  

The next stage is wind tunnel testing, which you can find here:  
[Project-Aero/grand-prix-wind-tunnel](../grand-prix-wind-tunnel)  

## That’s all for this sprint lap. Time to take the next corner 😉

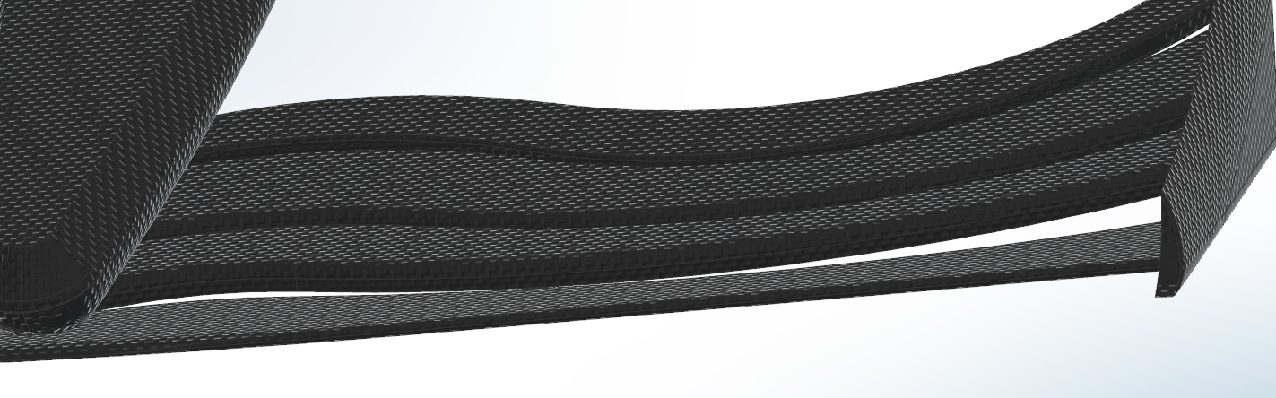
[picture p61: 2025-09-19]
sprint-3D-printing/images/flapfix.png
